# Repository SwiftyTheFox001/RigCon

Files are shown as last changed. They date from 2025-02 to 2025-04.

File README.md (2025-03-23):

# RigCon
Extension Board for the ClockworkPI uConsole to connect ham radio equiptment

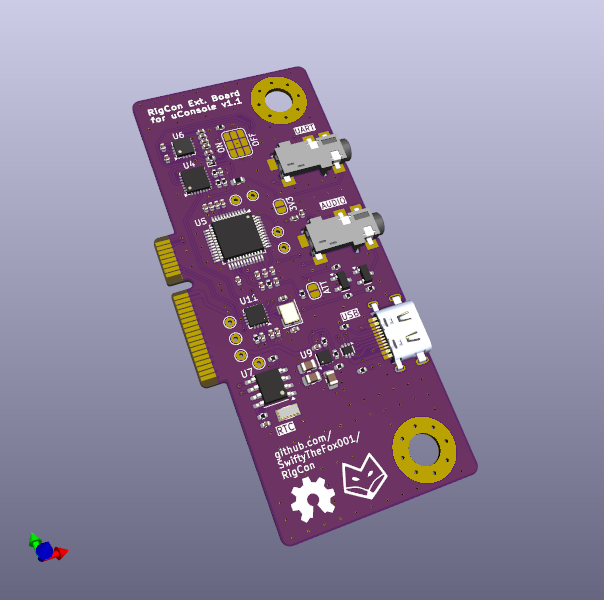
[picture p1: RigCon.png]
PCB


## Features
- Rig Interface equal to the DigiRig
 - Audio interface + PTT (2,5mm Audio Jack)
 - UART interface (2,5mm Audio Jack)
- Additional external USB-C Port (500mA max)
- RTC with Backup Battery (CR1220)

## Production

### JLC PCB
The main PCB can be ordered nearly assembled via JLC PCB.
- PCB settings:
 - Load .zip file from the "Production" folder
 - PCB Thickness: 1mm
 - Surface Finish: ENIG (recommended because of the edge connector)
- Assembly:
 - use bom_JLC.csv and positions_JLC.csv from the  "Production" folder
 - Check rotation of chips THRICE! Rotate them so, that the pink dot is alligned with the white arrows.

### DigiKey
The battery clip, the two jacks and the USB port were ordered seperately from Digikey. See "Production/bom_complete.csv" for the product names or check in KiCAD directly.

These parts need to be soldered manually. Drop a bit of solder on the GND pin of the bettery clip to ensure that the pad is contacted properly.
 
## Setup the RTC
Follow the tutorial here: https://learn.adafruit.com/adding-a-real-time-clock-to-raspberry-pi/set-up-and-test-i2c
The used RTC is a pcf8523!

## Version History
### v1.1
Fixes of v1.0 applied to schematic, not re-ordered YET

Changes from RigCon version 1.0 to 1.1:
- changed clock crystal footprint
- removed I2C pullup resistor footprints (was DNP before)
- removed unneccessary load caps for clock crystal (RTC has internal ones)
- changed cap value on CM108B pin 37 to 10uF (NECESSARY!)
- removed GND connectrio on CM108B pin 16 SDIN (optional, simplified)

Added directory FrontPanel/ with dxf, openSCAD and stl files
Added Schematic to main dir
Added Render Pic of PCB to main dir

### v1.0
First ordered version.

## This work is based on other projects!
[DigiRig-mobile](https://github.com/softcomplex/Digirig-Mobile) ([v1.9](https://github.com/softcomplex/Digirig-Mobile/tree/6721ff3781d7879b822c3f6550d4fcae7a4c0a2a)) (GNU GPL v3)
To provide an audio, ptt and uart interface for digital modes for ham radio. The CM108 was replaced with an CM108B and the 2-port USB controller was replaced with a 4-port USB controller to accomodate the additional external USB Port. The pinout of the audio jacks, solder pads for configuration and test pins were reused 1:1 to allow an easy reuse of exisiting peripherals and support for a wide range of transceivers.

[uconsole-expansion-card-template-kicad](https://github.com/PotatoMania/uconsole-expansion-card-template-kicad) ([used Version](https://github.com/PotatoMania/uconsole-expansion-card-template-kicad/tree/a174627fb24a4a155137b862d881c7e6f08ff017)) (CC BY-SA 4.0) 
PCB Outline, speakers, M.2 connector and mounting hole placements. I Changed to shape of mounting holes and the speaker pads, but all measurements provided by the original were correct.

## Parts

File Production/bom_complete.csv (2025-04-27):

Reference | Value | Footprint | DNP | LCSC | DigiKeyNr
C1,C3,C9,C17,C18,C20,C21,C22 | 10uF | Capacitor_SMD:C_0402_1005Metric |  | C15525
C2,C4,C5,C8,C10,C11,C12,C13,C14,C16,C19,C27 | 100nF | Capacitor_SMD:C_0402_1005Metric |  | C1525
C6,C7 | 10pF | Capacitor_SMD:C_0402_1005Metric |  | C1557
C15,C29 | 1uF | Capacitor_SMD:C_0402_1005Metric |  | C52923
C23,C24 | 27pF | Capacitor_SMD:C_0402_1005Metric |  | C1557
C28,C31,C32 | 47uF | Capacitor_SMD:C_0805_2012Metric |  | C16780
C30 | 4.7uF | Capacitor_SMD:C_0402_1005Metric |  | C23733
D1 | GS2005ELD | Diode_SMD:D_SOD-923 |  | C91106
Q1,Q2 | MMBT5551L | Package_TO_SOT_SMD:SOT-23 |  | C41095
R1,R15,R16,R17 | 12K | Resistor_SMD:R_0402_1005Metric |  | C25752
R2 | 27K | Resistor_SMD:R_0402_1005Metric
R3,R4,R5 | 100k | Resistor_SMD:R_0402_1005Metric
R6 | 10k | Resistor_SMD:R_0402_1005Metric
R7 | 1k | Resistor_SMD:R_0402_1005Metric
R8 | 22k | Resistor_SMD:R_0402_1005Metric
R11,R12 | 33 | Resistor_SMD:R_0402_1005Metric
R18,R19 | 100K | Resistor_SMD:R_0402_1005Metric
R22 | 47k | Resistor_SMD:R_0402_1005Metric
R23,R24 | 56k | Resistor_SMD:R_0402_1005Metric
TH1 | 0.02A | Resistor_SMD:R_0603_1608Metric |  | C914089
U4 | CP2102N-A02-GQFN24 | Package_DFN_QFN:QFN-24-1EP_4x4mm_P0.5mm_EP2.6x2.6mm |  | C969151
U5 | CM108B | Package_QFP:LQFP-48_7x7mm_P0.5mm |  | C371347
U6 | ADM3101E | Package_DFN_QFN:QFN-12-1EP_3x3mm_P0.51mm_EP1.45x1.45mm |  | C514336
U7 | PCF8523T | Package_SO:SOIC-8_3.9x4.9mm_P1.27mm |  | C2651516
U9 | TPS2553-1 | Package_SON:WSON-6-1EP_2x2mm_P0.65mm_EP1x1.6mm |  | C411878
U10 | USBLC6-2P6 | Package_TO_SOT_SMD:SOT-666 |  | C15999
U11 | CH334P | Package_DFN_QFN:QFN-16-1EP_3x3mm_P0.5mm_EP1.7x1.7mm_ThermalVias |  | C5373042
Y1 | 12MHz | Crystal:Crystal_SMD_3225-4Pin_3.2x2.5mm |  | C20617575
Y2 | 32,768 kHz | Crystal:Crystal_SMD_3215-2Pin_3.2x1.5mm |  | C97604

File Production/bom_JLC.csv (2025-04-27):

Designator | Footprint | Quantity | Value | LCSC Part #
C1, C17, C18, C20, C21, C22, C3, C9 | 0402 | 8 | 10uF | C15525
C10, C11, C12, C13, C14, C16, C19, C2, C27, C4, C5, C8 | 0402 | 12 | 100nF | C1525
C15, C29 | 0402 | 2 | 1uF | C52923
C23, C24 | 0402 | 2 | 27pF | C1557
C28, C31, C32 | 0805 | 3 | 47uF | C16780
C30 | 0402 | 1 | 4.7uF | C23733
C6, C7 | 0402 | 2 | 10pF | C1557
D1 | D_SOD-923 | 1 | GS2005ELD | C91106
Q1, Q2 | SOT-23 | 2 | MMBT5551L | C41095
R1, R15, R16, R17 | 0402 | 4 | 12K | C25752
R11, R12 | 0402 | 2 | 33
R18, R19, R3, R4, R5 | 0402 | 5 | 100K
R2 | 0402 | 1 | 27K
R22 | 0402 | 1 | 47k
R23, R24 | 0402 | 2 | 56k
R6 | 0402 | 1 | 10k
R7 | 0402 | 1 | 1k
R8 | 0402 | 1 | 22k
TH1 | 0603 | 1 | 0.02A | C914089
U10 | SOT-666 | 1 | USBLC6-2P6 | C15999
U11 | QFN-16-1EP_3x3mm_P0.5mm_EP1.7x1.7mm_ThermalVias | 1 | CH334P | C5373042
U4 | QFN-24-1EP_4x4mm_P0.5mm_EP2.6x2.6mm | 1 | CP2102N-A02-GQFN24 | C969151
U5 | LQFP-48_7x7mm_P0.5mm | 1 | CM108B | C371347
U6 | QFN-12-1EP_3x3mm_P0.51mm_EP1.45x1.45mm | 1 | ADM3101E | C514336
U7 | SOIC-8_3.9x4.9mm_P1.27mm | 1 | PCF8523T | C2651516
U9 | WSON-6-1EP_2x2mm_P0.65mm_EP1x1.6mm | 1 | TPS2553-1 | C411878
Y1 | Crystal_SMD_3225-4Pin_3.2x2.5mm | 1 | 12MHz | C20617575
Y2 | Crystal_SMD_3215-2Pin_3.2x1.5mm | 1 | 32,768 kHz | C97604

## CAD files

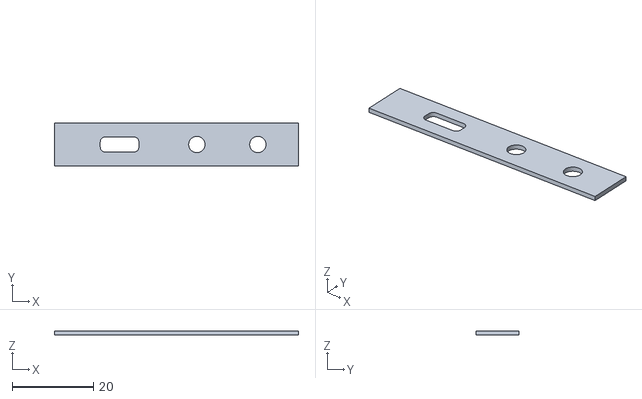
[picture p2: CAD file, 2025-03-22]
FrontPanel/front_panel.stl
60.0 x 10.5 x 1.00

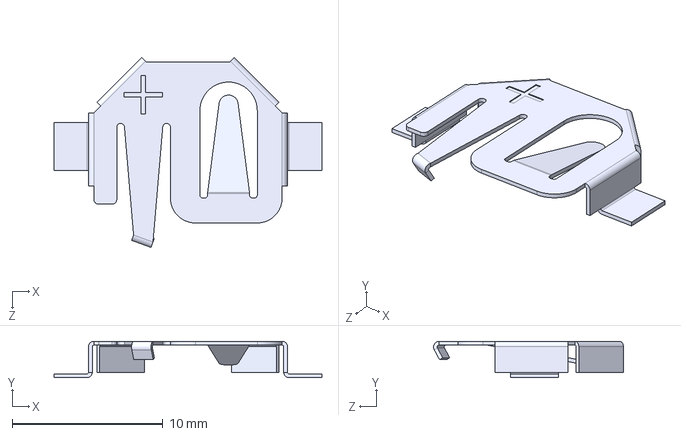
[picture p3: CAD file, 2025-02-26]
KiCAD/BK_940/BK-940.step
17.8 x 2.41 x 12.6 mm

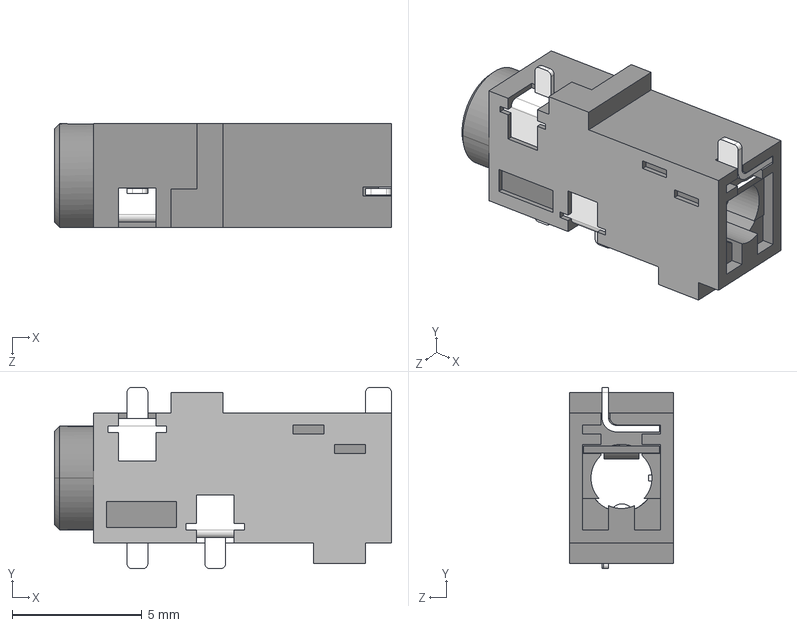
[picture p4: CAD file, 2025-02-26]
KiCAD/SJ2_25774A_SMT_TR/SJ2-25774A-SMT-TR.step
13.0 x 7.00 x 4.00 mm

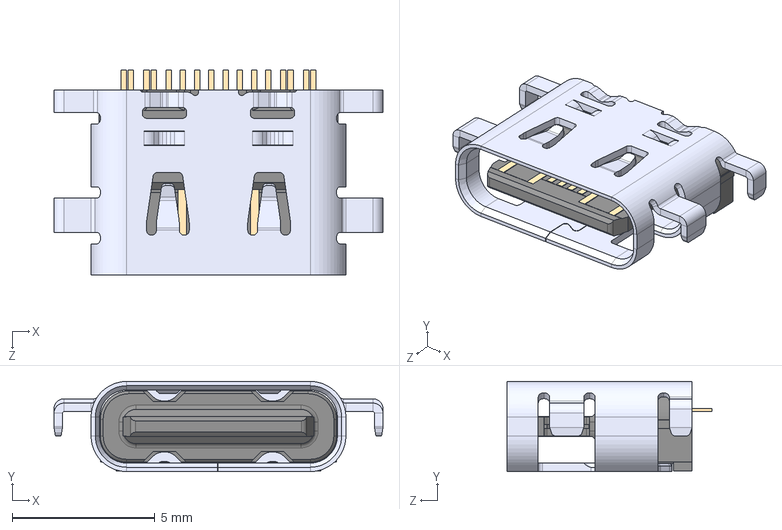
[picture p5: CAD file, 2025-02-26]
KiCAD/USB4520/USB4520-03-1-A_REVA.step
11.5 x 3.16 x 7.20 mm

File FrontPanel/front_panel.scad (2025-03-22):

linear_extrude(height=1)
    import(file="./front_panel.dxf", layer="Plate", $fn=64);

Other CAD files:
FrontPanel/front_panel.dxf

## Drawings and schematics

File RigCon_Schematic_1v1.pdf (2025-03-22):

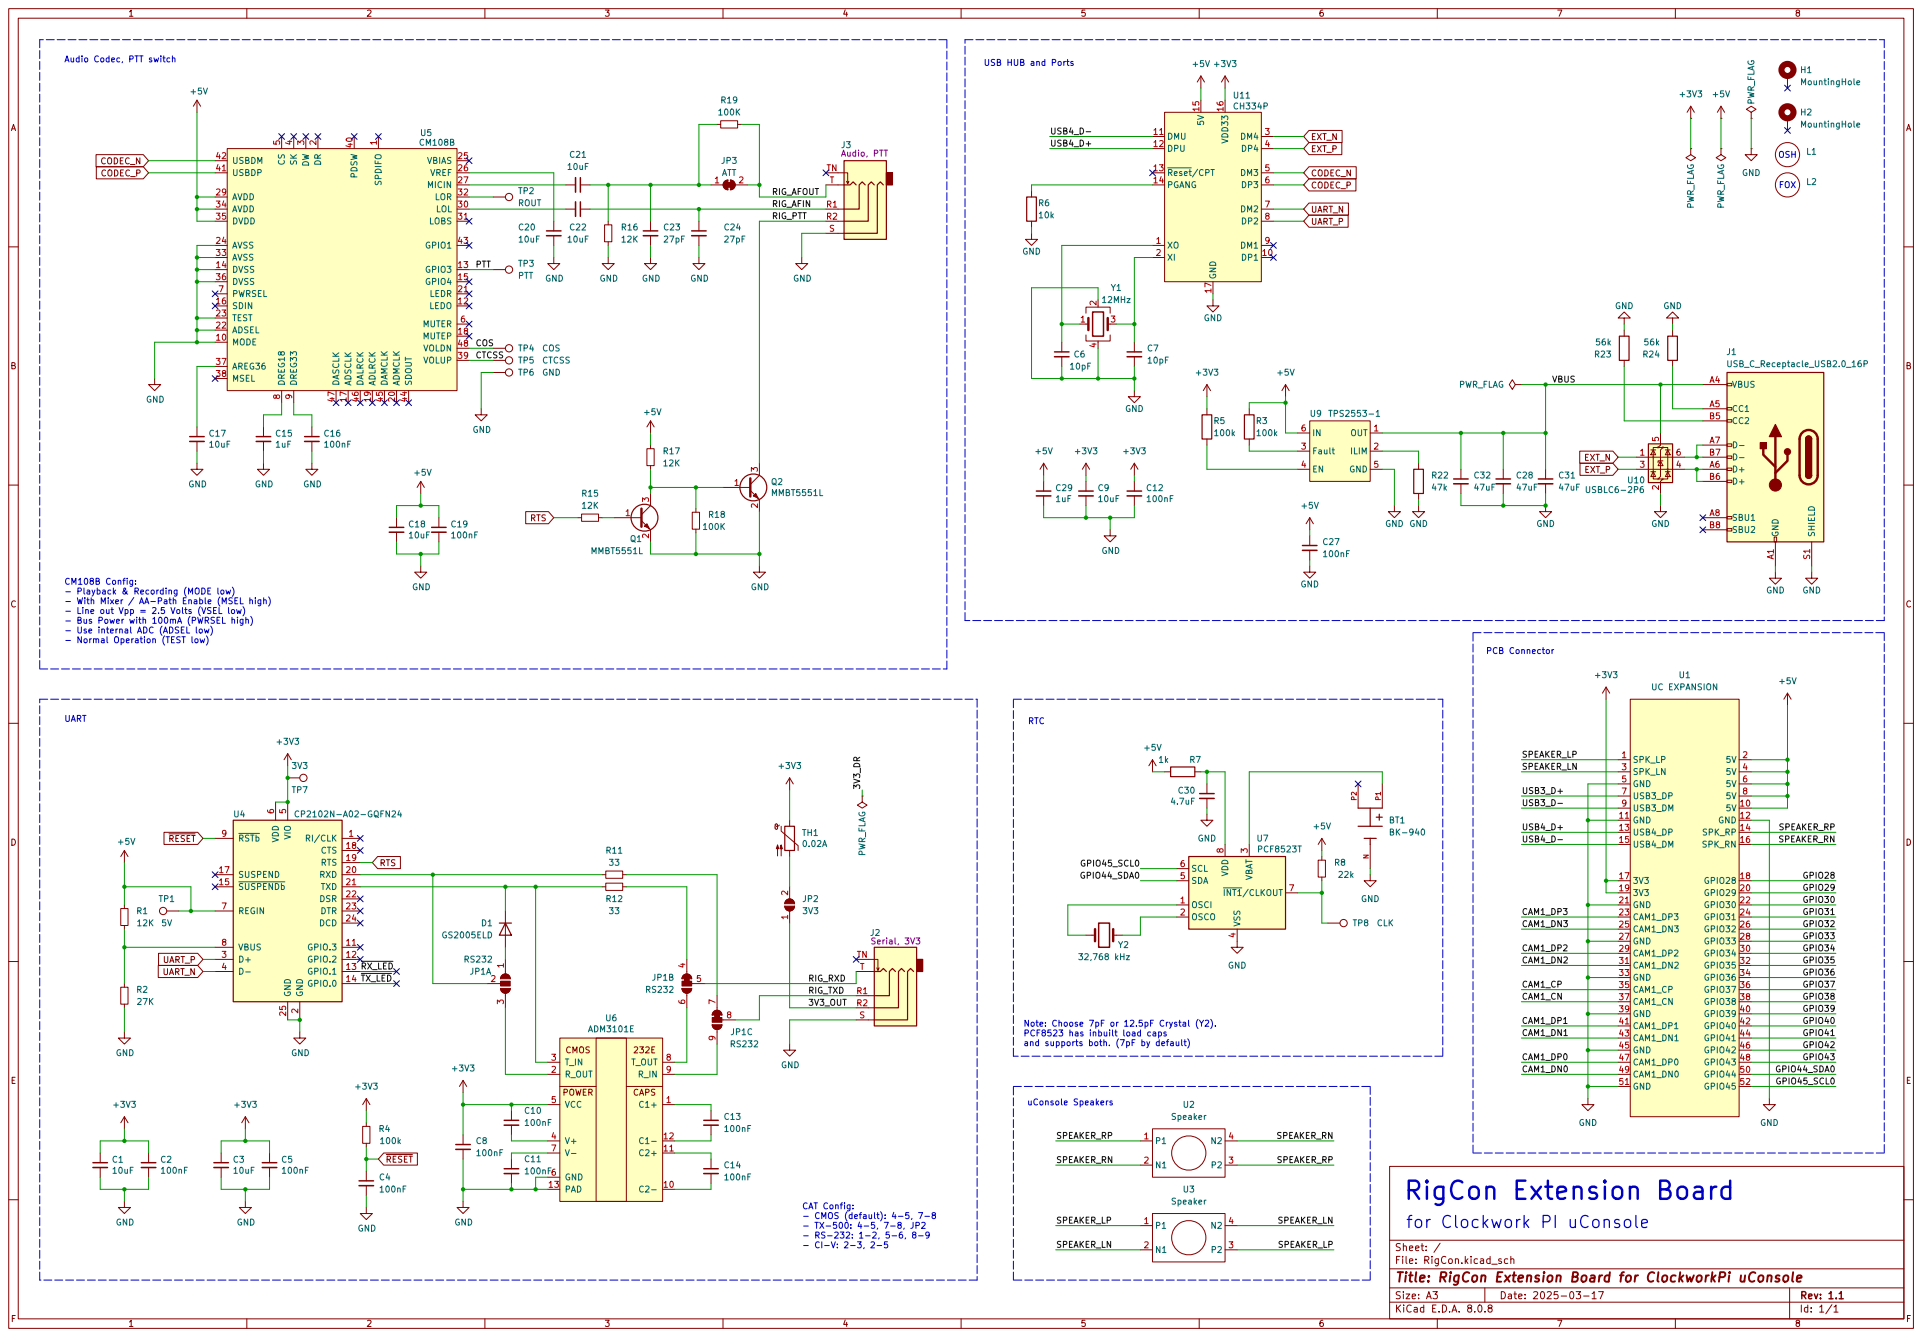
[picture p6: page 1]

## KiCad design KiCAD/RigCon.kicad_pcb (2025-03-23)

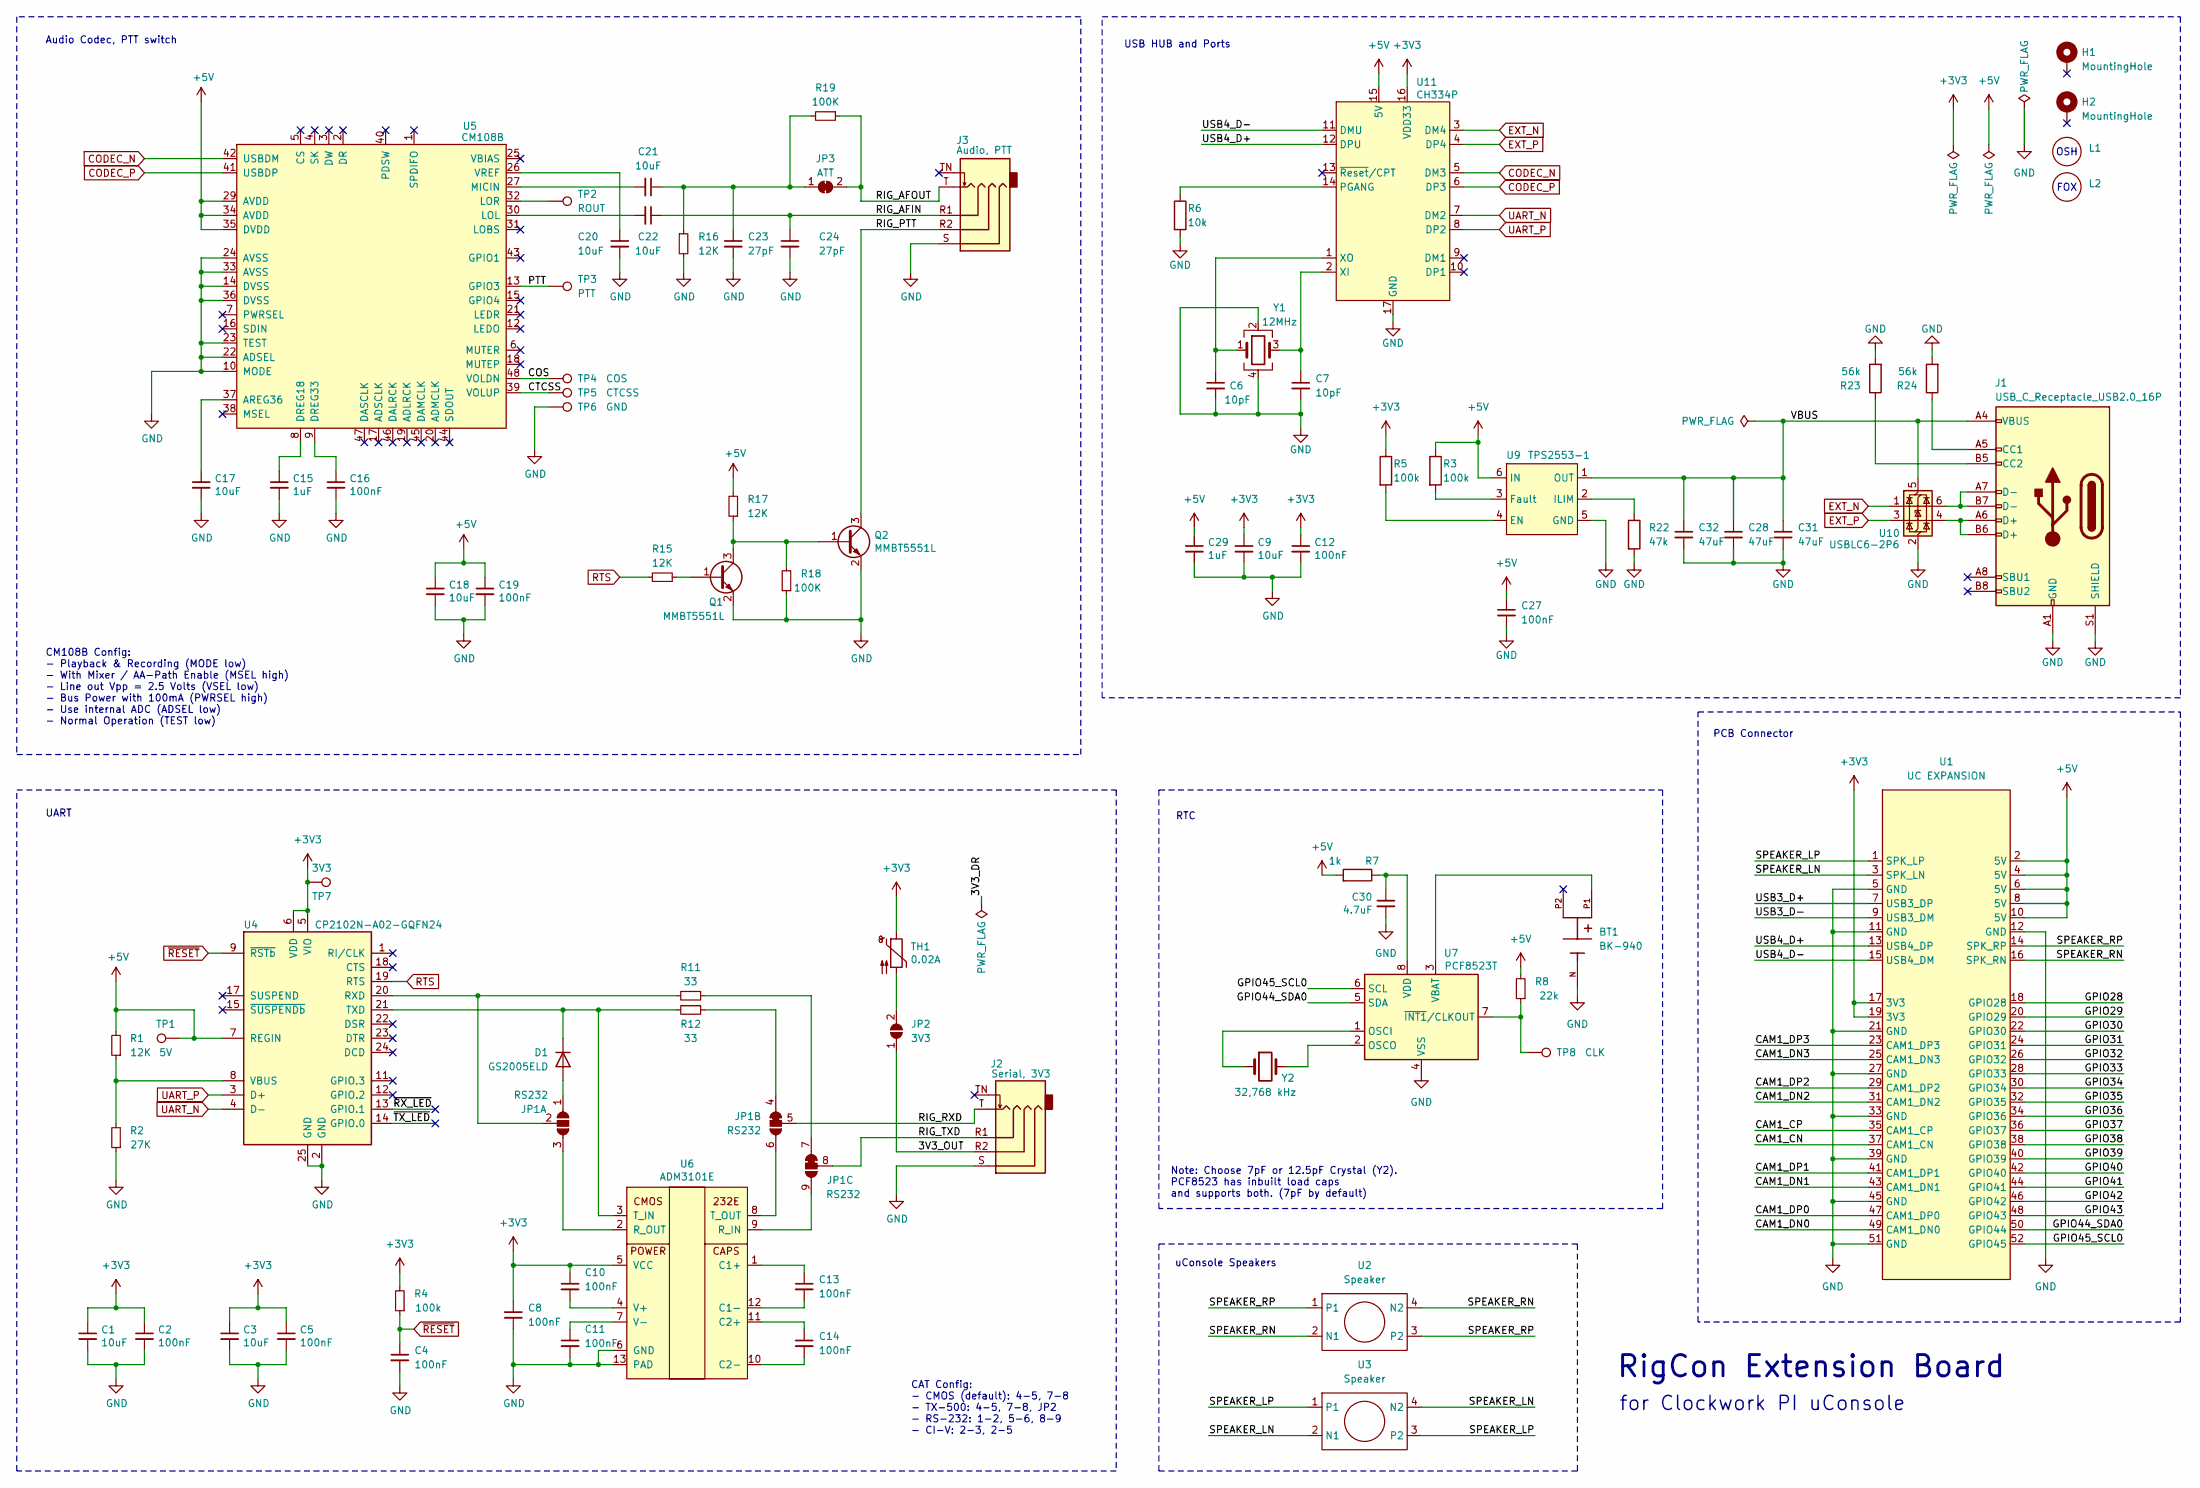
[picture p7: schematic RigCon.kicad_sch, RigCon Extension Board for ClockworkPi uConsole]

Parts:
BT1: BK-940; MPD_BK-940; PARTREV 04/15/21; DigiKeyNr BK-940
C1, C3, C9, C17, C18, C20, C21, C22: 10uF; C_0402_1005Metric; LCSC C15525
C2, C4, C5, C8, C10, C11, C12, C13, C14, C16, C19, C27: 100nF; C_0402_1005Metric; LCSC C1525
C6, C7: 10pF; C_0402_1005Metric; LCSC C1557
C15, C29: 1uF; C_0402_1005Metric; LCSC C52923
C23, C24: 27pF; C_0402_1005Metric; LCSC C1557
C28, C31, C32: 47uF; C_0805_2012Metric; LCSC C16780
C30: 4.7uF; C_0402_1005Metric; LCSC C23733
D1: GS2005ELD; D_SOD-923; LCSC C91106
H1, H2: MountingHole; MountingHole_5mm_Pad_Via
J1: USB_C_Receptacle_USB2.0_16P; USB-4520-03-X-A; DigiKeyNr USB4520-03-1-A
J2, J3: PJ-320A; SJ2-25774x-SMT; DigiKeyNr CP-SJ2-25774A-SMT
JP1: RS232; SolderJumper9-BCu
JP2: 3V3; SolderJumper2-BCu
JP3: ATT; SolderJumper-BCu-Bridged
L1: OSHW-Symbol_6.7x6mm_SilkScreen
L2: Logo_Fox
Q1, Q2: MMBT5551L; SOT-23; LCSC C41095
R1, R15, R16, R17: 12K; R_0402_1005Metric; LCSC C25752
R2: 27K; R_0402_1005Metric
R3, R4, R5: 100k; R_0402_1005Metric
R6: 10k; R_0402_1005Metric
R7: 1k; R_0402_1005Metric
R8: 22k; R_0402_1005Metric
R11, R12: 33; R_0402_1005Metric
R18, R19: 100K; R_0402_1005Metric
R22: 47k; R_0402_1005Metric
R23, R24: 56k; R_0402_1005Metric
TH1: 0.02A; R_0603_1608Metric; LCSC C914089
TP1: 5V; TestPoint_THTPad_D1.5mm_Drill0.7mm
TP2: ROUT; TestPoint_THTPad_D1.5mm_Drill0.7mm
TP3: PTT; TestPoint_THTPad_D1.5mm_Drill0.7mm
TP4: COS; TestPoint_THTPad_D1.5mm_Drill0.7mm
TP5: CTCSS; TestPoint_THTPad_D1.5mm_Drill0.7mm
TP6: GND; TestPoint_THTPad_D1.5mm_Drill0.7mm
TP7: 3V3; TestPoint_THTPad_D1.5mm_Drill0.7mm
TP8: CLK; TestPoint_THTPad_D1.5mm_Drill0.7mm
U1: UC EXPANSION; edge-minipcie
U2, U3: Speaker; speaker pads
U4: CP2102N-A02-GQFN24; QFN-24-1EP_4x4mm_P0.5mm_EP2.6x2.6mm; LCSC C969151
U5: CM108B; LQFP-48_7x7mm_P0.5mm; LCSC C371347
U6: ADM3101E; QFN-12-1EP_3x3mm_P0.51mm_EP1.45x1.45mm; LCSC C514336
U7: PCF8523T; SOIC-8_3.9x4.9mm_P1.27mm; LCSC C2651516
U9: TPS2553-1; WSON-6-1EP_2x2mm_P0.65mm_EP1x1.6mm; LCSC C411878
U10: USBLC6-2P6; SOT-666; LCSC C15999
U11: CH334P; QFN-16-1EP_3x3mm_P0.5mm_EP1.7x1.7mm_ThermalVias; LCSC C5373042
Y1: 12MHz; Crystal_SMD_3225-4Pin_3.2x2.5mm; LCSC C20617575
Y2: 32,768 kHz; Crystal_SMD_3215-2Pin_3.2x1.5mm; LCSC C97604

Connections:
+3V3: C1.1, C2.1, C3.1, C5.1, C8.1, C9.1, C10.1, C12.1, R4.2, R5.1, TH1.1, TP7.1, U1.17 (3V3), U1.19 (3V3), U4.5 (VIO), U4.6 (VDD), U6.5 (VCC), U11.16 (VDD33)
+5V: C18.1, C19.1, C27.1, C29.1, R1.2, R3.1, R7.2, R8.2, R17.2, TP1.1, U1.2 (5V), U1.4 (5V), U1.6 (5V), U1.8 (5V), U1.10 (5V), U4.7 (REGIN), U5.29 (AVDD), U5.34 (AVDD), U5.35 (DVDD), U9.6 (IN), U11.15 (5V)
/3V3_OUT: J2.R2, JP2.1 (A)
/CAM1_CN: U1.37 (CAM1_CN)
/CAM1_CP: U1.35 (CAM1_CP)
/CAM1_DN0: U1.49 (CAM1_DN0)
/CAM1_DN1: U1.43 (CAM1_DN1)
/CAM1_DN2: U1.31 (CAM1_DN2)
/CAM1_DN3: U1.25 (CAM1_DN3)
/CAM1_DP0: U1.47 (CAM1_DP0)
/CAM1_DP1: U1.41 (CAM1_DP1)
/CAM1_DP2: U1.29 (CAM1_DP2)
/CAM1_DP3: U1.23 (CAM1_DP3)
/COS: TP4.1, U5.48 (VOLDN)
/CTCSS: TP5.1, U5.39 (VOLUP)
/GPIO28: U1.18 (GPIO28)
/GPIO29: U1.20 (GPIO29)
/GPIO30: U1.22 (GPIO30)
/GPIO31: U1.24 (GPIO31)
/GPIO32: U1.26 (GPIO32)
/GPIO33: U1.28 (GPIO33)
/GPIO34: U1.30 (GPIO34)
/GPIO35: U1.32 (GPIO35)
/GPIO36: U1.34 (GPIO36)
/GPIO37: U1.36 (GPIO37)
/GPIO38: U1.38 (GPIO38)
/GPIO39: U1.40 (GPIO39)
/GPIO40: U1.42 (GPIO40)
/GPIO41: U1.44 (GPIO41)
/GPIO42: U1.46 (GPIO42)
/GPIO43: U1.48 (GPIO43)
/GPIO44_SDA0: U1.50 (GPIO44), U7.5 (SDA)
/GPIO45_SCL0: U1.52 (GPIO45), U7.6 (SCL)
/PTT: TP3.1, U5.13 (GPIO3)
/RIG_AFIN: C22.1, C24.1, J3.R1
/RIG_AFOUT: J3.T, JP3.2 (B), R19.1
/RIG_PTT: J3.R2, Q2.3 (C)
/RIG_RXD: J2.T, JP1.5 (B)
/RIG_TXD: J2.R1, JP1.8 (B)
/SPEAKER_LN: U1.3 (SPK_LN), U3.2 (N1), U3.4 (N2)
/SPEAKER_LP: U1.1 (SPK_LP), U3.1, U3.3 (P2)
/SPEAKER_RN: U1.16 (SPK_RN), U2.2 (N1), U2.4 (N2)
/SPEAKER_RP: U1.14 (SPK_RP), U2.1, U2.3 (P2)
/USB3_D+: U1.7 (USB3_DP)
/USB3_D-: U1.9 (USB3_DM)
/USB4_D+: U1.13 (USB4_DP), U11.12 (DPU)
/USB4_D-: U1.15 (USB4_DM), U11.11 (DMU)
/VBUS: C28.1, C31.1, C32.1, J1.A4 (VBUS), J1.A9 (VBUS), J1.B4 (VBUS), J1.B9 (VBUS), U9.1 (OUT), U10.5 (VBUS)
/~RX_LED: U4.13 (GPIO.1)
/~TX_LED: U4.14 (GPIO.0)
CODEC_N: U5.42 (USBDM), U11.5 (DM3)
CODEC_P: U5.41 (USBDP), U11.6 (DP3)
EXT_N: U10.1 (I/O1), U11.3 (DM4)
EXT_P: U10.3 (I/O2), U11.4 (DP4)
GND: BT1.N, C1.2, C2.2, C3.2, C4.2, C5.2, C6.2, C7.2, C8.2, C9.2, C11.2, C12.2, C15.2, C16.2, C17.2, C18.2, C19.2, C20.2, C23.2, C24.2, C27.2, C28.2, C29.2, C30.2, C31.2, C32.2, J1.A1 (GND), J1.A12 (GND), J1.B1 (GND), J1.B12 (GND), J1.S1 (SHIELD), J2.S, J3.S, Q1.2 (E), Q2.2 (E), R2.1, R6.2, R16.2, R18.1, R22.2, R23.2, R24.2, TP6.1, U1.5 (GND), U1.11 (GND), U1.12 (GND), U1.21 (GND), U1.27 (GND), U1.33 (GND), U1.39 (GND), U1.45 (GND), U1.51 (GND), U4.2 (GND), U4.25 (GND), U5.10 (MODE), U5.14 (DVSS), U5.22 (ADSEL), U5.23 (TEST), U5.24 (AVSS), U5.33 (AVSS), U5.36 (DVSS), U6.6 (GND), U6.13 (PAD), U7.4 (VSS), U9.5 (GND), U9.7 (GND), U10.2 (GND), U11.17 (GND), Y1.2, Y1.4
unnamed: D1.2 (A), JP1.1 (A)
unnamed: D1.1 (K), R12.2, U4.21 (TXD), U6.3 (T_IN)
unnamed: J1.A5 (CC1), R24.1
unnamed: J1.B5 (CC2), R23.1
unnamed: J1.A6 (D+), J1.B6 (D+), U10.4 (I/O2)
unnamed: J1.A7 (D-), J1.B7 (D-), U10.6 (I/O1)
unnamed: JP1.2 (B), R11.2, U4.20 (RXD)
unnamed: JP1.3 (C), U6.2 (R_OUT)
unnamed: JP1.4 (A), R12.1
unnamed: JP1.6 (C), U6.8 (T_OUT)
unnamed: JP1.7 (A), R11.1
unnamed: JP1.9 (C), U6.9 (R_IN)
unnamed: JP2.2 (B), TH1.2
unnamed: C21.1, C23.1, JP3.1 (A), R16.1, R19.2
unnamed: Q1.1 (B), R15.2
unnamed: Q1.3 (C), Q2.1 (B), R17.1, R18.2
unnamed: R1.1, R2.2, U4.8 (VBUS)
unnamed: C17.1, U5.37 (AREG36)
unnamed: C15.1, U5.8 (DREG18)
unnamed: C16.1, U5.9 (DREG33)
unnamed: C22.2, U5.30 (LOL)
unnamed: TP2.1, U5.32 (LOR)
unnamed: C21.2, U5.27 (MICIN)
unnamed: C20.1, U5.26 (VREF)
unnamed: C13.1, U6.1 (C1+)
unnamed: C13.2, U6.12 (C1-)
unnamed: C14.1, U6.11 (C2+)
unnamed: C14.2, U6.10 (C2-)
unnamed: C10.2, U6.4 (V+)
unnamed: C11.1, U6.7 (V-)
unnamed: U7.1 (OSCI), Y2.1
unnamed: U7.2 (OSCO), Y2.2
unnamed: BT1.P1, U7.3 (VBAT)
unnamed: C30.1, R7.1, U7.8 (VDD)
unnamed: R8.1, TP8.1, U7.7 (~INT1/CLKOUT)
unnamed: R5.2, U9.4 (EN)
unnamed: R3.2, U9.3 (Fault)
unnamed: R22.1, U9.2 (ILIM)
unnamed: R6.1, U11.14 (PGANG)
unnamed: C7.1, U11.2 (XI), Y1.3
unnamed: C6.1, U11.1 (XO), Y1.1
RTS: R15.1, U4.19 (RTS)
UART_N: U4.4 (D-), U11.7 (DM2)
UART_P: U4.3 (D+), U11.8 (DP2)
~RESET: C4.1, R4.1, U4.9 (~RSTb)

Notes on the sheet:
PCB Connector
UART
Note: Choose 7pF or 12.5pF Crystal (Y2). PCF8523 has inbuilt load caps and supports both. (7pF by default)
Audio Codec, PTT switch
CAT Config: - CMOS (default): 4-5, 7-8 - TX-500: 4-5, 7-8, JP2 - RS-232: 1-2, 5-6, 8-9 - CI-V: 2-3, 2-5
for Clockwork PI uConsole
uConsole Speakers
OSH
FOX
RigCon Extension Board
USB HUB and Ports
CM108B Config: - Playback & Recording (MODE low) - With Mixer / AA-Path Enable (MSEL high) - Line out Vpp = 2.5 Volts (VSEL low) - Bus Power with 100mA (PWRSEL high) - Use internal ADC (ADSEL low) - Normal Operation (TEST low)
RTC

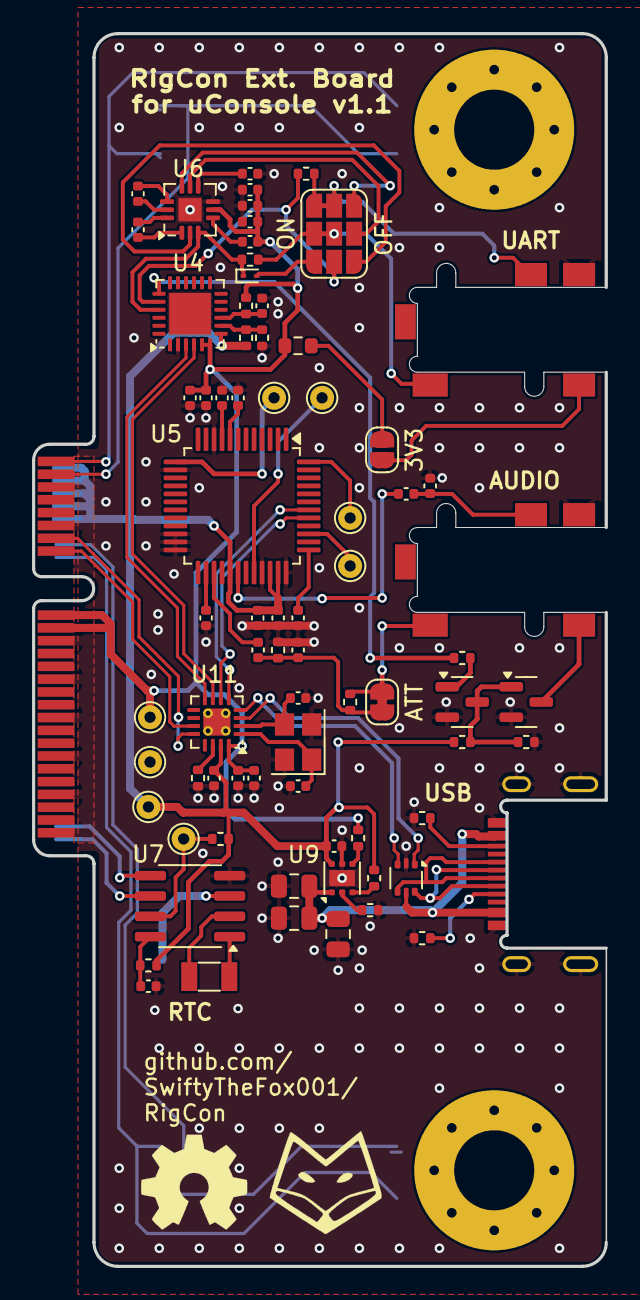
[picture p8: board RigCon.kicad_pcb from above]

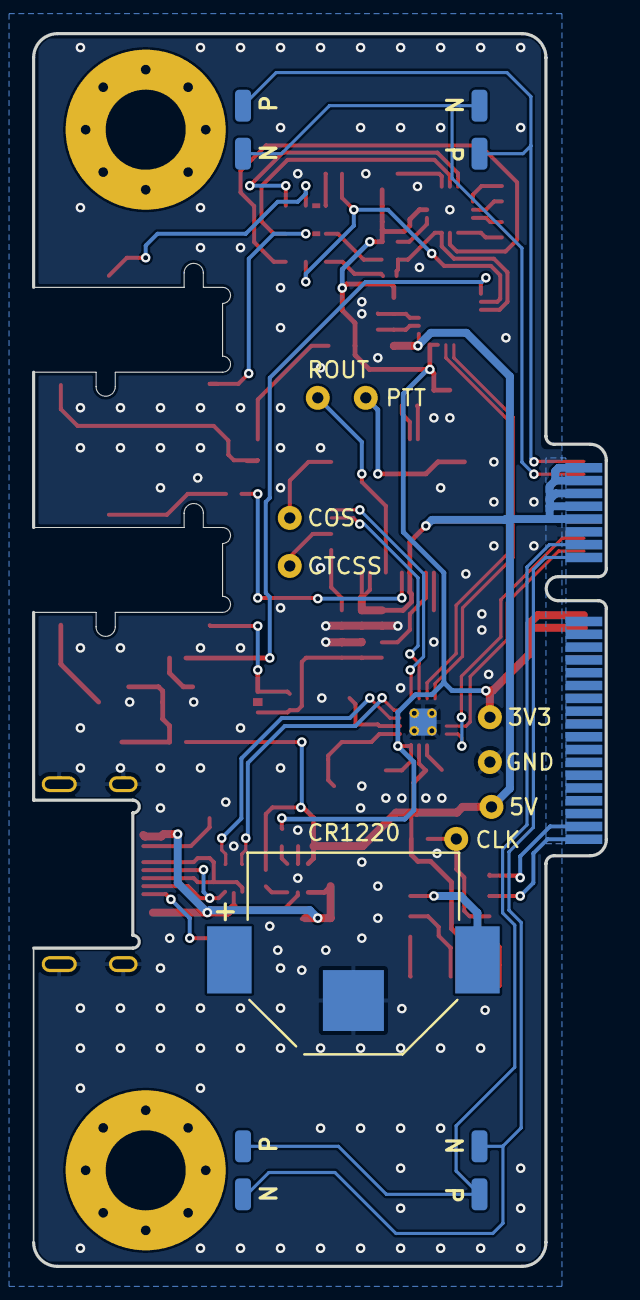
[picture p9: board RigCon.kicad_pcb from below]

Board: 2 copper layers, 35.8 x 77.0 mm, 83 parts (6 on the bottom side), 70 nets.

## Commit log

2025-02-26 First commit with KiCAD project and datasheets
    [BK-940.step, SJ2-25773B-SMT-TR.step, SJ2-25774A-SMT-TR.step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]
2025-02-26 Renamed KiCAD Project to "RigCon"
    [RigCon.kicad_pcb, RigCon.kicad_sch, SJ2-25773B-SMT-TR.step]
2025-02-26 Updated PCB: routing added fox logo correct symbol for mounting hole with pad
    [RigCon.kicad_pcb, RigCon.kicad_sch]
2025-02-26 Removed DigiRig Footprint Library Added github URL on silkscreen
    [RigCon.kicad_pcb]
2025-02-26 Fixed Errors in Labels excluded parts from position file and bom
    [RigCon.kicad_pcb, RigCon.kicad_sch]
2025-02-27 Version of prototype order (v1.0)
    Updated a few Texts and Order Numbers
    Updated TPS2553 to TPS2553-1 (Latched version)
    [RigCon.kicad_pcb, RigCon.kicad_sch]
2025-03-22 Changes from RigCon version 1.0 to 1.1:
    - changed clock crystal footprint
    - removed I2C pullup resistor footprints (was DNP before)
    - removed unneccessary load caps for clock crystal (RTC has internal ones)
    - changed cap value on CM108B pin 37 to 10uF (NECESSARY!)
    - removed GND connectrio on CM108B pin 16 SDIN (optional, simplified)
    Added directory FrontPanel/ with dxf, openSCAD and stl files
    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
    [RigCon.kicad_pcb, RigCon.kicad_sch, front_panel.dxf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]
2025-03-22 PCB: Minor Changes Updated Document Information (Header, Version, Date)
    [RigCon.kicad_pcb, RigCon.kicad_sch]
2025-03-23 - Added Gerber, BOM & part positions for production - improved README
    [RigCon.kicad_pcb, RigCon.kicad_sch]
2025-04-27 Added missing BOM files that were ommited by the .gitignore
    [bom_JLC.csv, bom_complete.csv, positions_JLC.csv]
